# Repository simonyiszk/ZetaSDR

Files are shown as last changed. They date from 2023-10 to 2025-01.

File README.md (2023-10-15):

# ZetaSDR
ZetaSDR HF rádióvevő extra funkciókkal kiegészítve (PLL, USB hangkártya)
zetasdr
Fejlesztői környezet: [https://github.com/Community-PIO-CH32V/platform-ch32v](https://github.com/Community-PIO-CH32V/platform-ch32v).\
Az elektronikai terveket [KiCad](https://www.kicad.org/) seítségével készítettem.

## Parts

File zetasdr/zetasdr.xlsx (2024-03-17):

Reference | Value | Datasheet | Footprint | Qty
C1,C3,C9,C13,C17 | 100n | ~ | Capacitor_SMD:C_0805_2012Metric_Pad1.18x1.45mm_HandSolder | 5
C2,C4 | 22p | ~ | Capacitor_SMD:C_0805_2012Metric_Pad1.18x1.45mm_HandSolder | 2
C5,C6,C7,C8 | 22n | ~ | Capacitor_THT:C_Disc_D3.0mm_W1.6mm_P2.50mm | 4
C10,C12 | 330p | ~ | Capacitor_THT:C_Disc_D3.0mm_W1.6mm_P2.50mm | 2
C11 | 100p | ~ | Capacitor_THT:C_Disc_D3.0mm_W1.6mm_P2.50mm | 1
C14,C15 | 1u | ~ | Capacitor_SMD:C_0805_2012Metric_Pad1.18x1.45mm_HandSolder | 2
C16 | 10u | ~ | Capacitor_THT:CP_Radial_D5.0mm_P2.50mm | 1
D1,D2 | LED | ~ | -- mixed values -- | 2
J1,J4,J9 | OSC | ~ | -- mixed values -- | 6
J2 | USB_B | ~ | Connector_USB:USB_B_Lumberg_2411_02_Horizontal | 1
J3 | USB | ~ | Connector_PinHeader_2.54mm:PinHeader_1x04_P2.54mm_Vertical | 1
J5 | Antenna | ~ | Connector_Coaxial:SMA_Amphenol_901-143_Horizontal | 1
J6 | AudioJack3_SwitchTR | ~ | Connector_Audio:Jack_3.5mm_CUI_SJ1-3525N_Horizontal | 1
J7 | ADC | ~ | Connector_PinHeader_2.54mm:PinHeader_1x04_P2.54mm_Vertical | 1
J8 | FILTER | ~ | Connector_PinHeader_2.54mm:PinHeader_1x04_P2.54mm_Vertical | 1
R1 | 10 | ~ | Resistor_SMD:R_0805_2012Metric_Pad1.20x1.40mm_HandSolder | 1
R2,R3,R7,R8 | 1k | ~ | -- mixed values -- | 4
R4,R5 | 5k1 | ~ | Resistor_THT:R_Axial_DIN0204_L3.6mm_D1.6mm_P5.08mm_Horizontal | 2
R6 | 1M | ~ | Resistor_SMD:R_0805_2012Metric_Pad1.20x1.40mm_HandSolder | 1
U1,U5 | 74AHCT1G14 | http://www.ti.com/lit/sg/scyt129e/scyt129e.pdf | Package_TO_SOT_SMD:SOT-23-5 | 2
U2 | 74HC74 | 74xx/74hc_hct74.pdf | Package_DIP:DIP-14_W7.62mm_Socket_LongPads | 1
U3 | 74HC4052 | http://www.intersil.com/content/dam/Intersil/documents/cd40/cd4051bms-52bms-53bms.pdf | Package_DIP:DIP-16_W7.62mm_Socket_LongPads | 1
U4 | NE5532 | http://www.ti.com/lit/ds/symlink/ne5532.pdf | Package_DIP:DIP-8_W7.62mm_Socket_LongPads | 1
X1 | 28.322MHz | http://cdn-reichelt.de/documents/datenblatt/B400/OSZI.pdf | Oscillator:Oscillator_DIP-8 | 1
Y1 | 14.3594MHz | ~ | Crystal:Crystal_HC49-4H_Vertical | 1
Oszci 40m-re | (7.0805 MHz)
C17 | 100n | ~ | Capacitor_SMD:C_0805_2012Metric_Pad1.18x1.45mm_HandSolder | 1
R8 | 1k | ~ | Resistor_SMD:R_0805_2012Metric_Pad1.20x1.40mm_HandSolder | 1
D2 | LED | ~ | LED_SMD:LED_0805_2012Metric_Pad1.15x1.40mm_HandSolder | 1
J9 | OSC | ~ | Connector_PinSocket_2.54mm:PinSocket_1x03_P2.54mm_Vertical | 2
X1 | 28.322MHz | ECS-2100AX-283.2 (Mouser) | Oscillator:Oscillator_DIP-8 | 1
Oszci 80 m-re | (3.5795 MHz)
C1 | 100n | ~ | Capacitor_SMD:C_0805_2012Metric_Pad1.18x1.45mm_HandSolder | 1
C2,C4 | 22p | ~ | Capacitor_SMD:C_0805_2012Metric_Pad1.18x1.45mm_HandSolder | 2
R1 | 10 | ~ | Resistor_SMD:R_0805_2012Metric_Pad1.20x1.40mm_HandSolder | 1
R6 | 1M | ~ | Resistor_SMD:R_0805_2012Metric_Pad1.20x1.40mm_HandSolder | 1
U1,U5 | 74AHCT1G14 | http://www.ti.com/lit/sg/scyt129e/scyt129e.pdf | Package_TO_SOT_SMD:SOT-23-5 | 2
Y1 | 14.3594MHz | ~ | Crystal:Crystal_HC49-4H_Vertical | 1
J4 | OSC | ~ | Connector_PinSocket_2.54mm:PinSocket_1x03_P2.54mm_Vertical | 2
Alappanel
C3,C9,C13 | 100n | ~ | Capacitor_SMD:C_0805_2012Metric_Pad1.18x1.45mm_HandSolder | 3
C5,C6,C7,C8 | 22n | ~ | Capacitor_THT:C_Disc_D3.0mm_W1.6mm_P2.50mm | 4
C10,C12 | 330p | ~ | Capacitor_THT:C_Disc_D3.0mm_W1.6mm_P2.50mm | 2
C11 | 100p | ~ | Capacitor_THT:C_Disc_D3.0mm_W1.6mm_P2.50mm | 1
C14,C15 | 1u | ~ | Capacitor_SMD:C_0805_2012Metric_Pad1.18x1.45mm_HandSolder | 2
C16 | 10u | ~ | Capacitor_THT:CP_Radial_D5.0mm_P2.50mm | 1
D1 | LED | ~ | LED_THT:LED_D3.0mm | 1
J1 | OSC | ~ | Connector_PinHeader_2.54mm:PinHeader_1x03_P2.54mm_Vertical | 2
J2 | USB_B | ~ | Connector_USB:USB_B_Lumberg_2411_02_Horizontal | 1
J3 | USB | ~ | Connector_PinHeader_2.54mm:PinHeader_1x04_P2.54mm_Vertical | 1
J5 | Antenna | ~ | Connector_Coaxial:SMA_Amphenol_901-143_Horizontal | 1
J6 | AudioJack3_SwitchTR | ~ | Connector_Audio:Jack_3.5mm_CUI_SJ1-3525N_Horizontal | 1
J7 | ADC | ~ | Connector_PinHeader_2.54mm:PinHeader_1x04_P2.54mm_Vertical | 1
J8 | FILTER | ~ | Connector_PinHeader_2.54mm:PinHeader_1x04_P2.54mm_Vertical | 1
R2,R3 | 1k | ~ | Resistor_THT:R_Axial_DIN0204_L3.6mm_D1.6mm_P5.08mm_Horizontal | 2
R7 | 1k | ~ | Resistor_SMD:R_0805_2012Metric_Pad1.20x1.40mm_HandSolder | 1
R4,R5 | 5k1 | ~ | Resistor_THT:R_Axial_DIN0204_L3.6mm_D1.6mm_P5.08mm_Horizontal | 2
U2 | 74HC74 | 74xx/74hc_hct74.pdf | Package_DIP:DIP-14_W7.62mm_Socket_LongPads | 1
U3 | 74HC4052 | http://www.intersil.com/content/dam/Intersil/documents/cd40/cd4051bms-52bms-53bms.pdf | Package_DIP:DIP-16_W7.62mm_Socket_LongPads | 1
U4 | NE5532 | http://www.ti.com/lit/ds/symlink/ne5532.pdf | Package_DIP:DIP-8_W7.62mm_Socket_LongPads | 1
Opcionális IC foglalatok:
U2 | 74HC74 | ~ | Package_DIP:DIP-14_W7.62mm_Socket_LongPads | 1
U3 | 74HC4052 | ~ | Package_DIP:DIP-16_W7.62mm_Socket_LongPads | 1
U4 | NE5532 | ~ | Package_DIP:DIP-8_W7.62mm_Socket_LongPads | 1

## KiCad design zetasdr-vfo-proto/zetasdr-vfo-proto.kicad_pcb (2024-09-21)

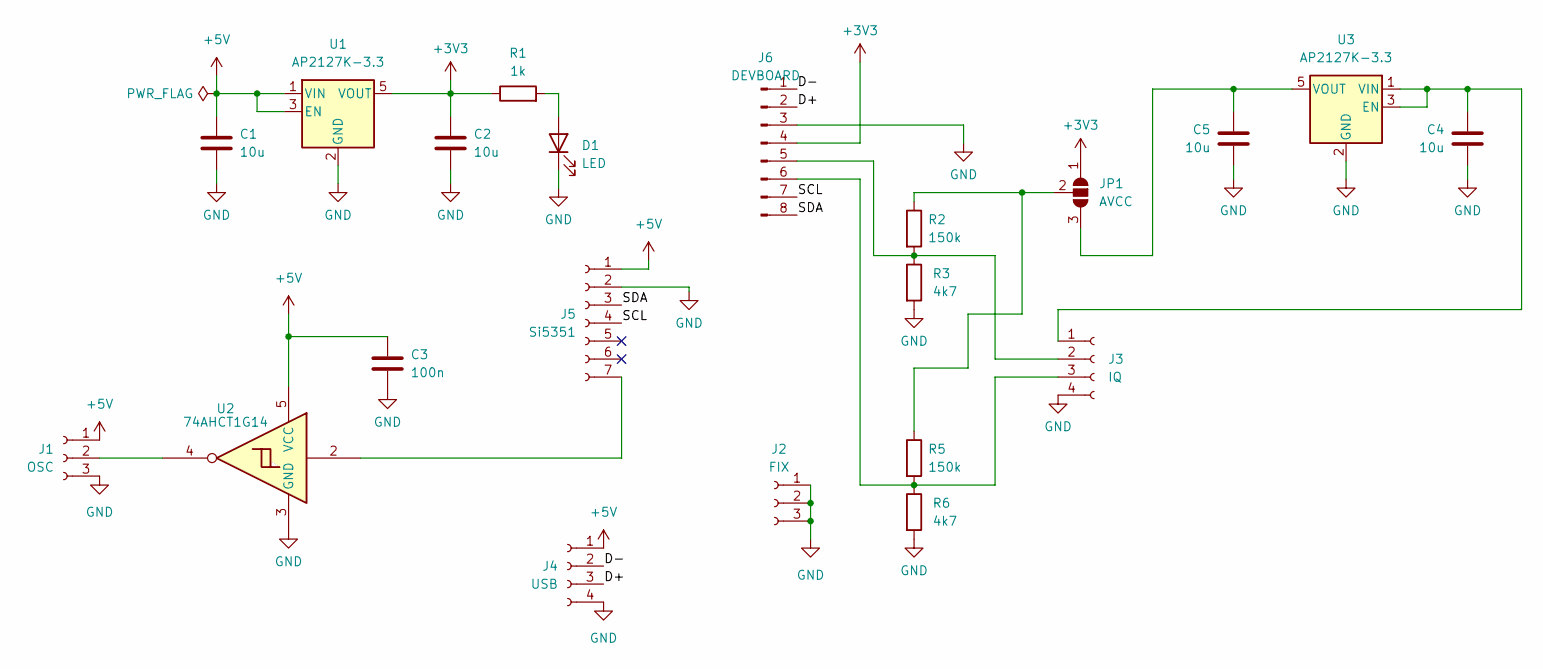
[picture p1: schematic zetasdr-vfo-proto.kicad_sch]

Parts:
C1, C2, C4, C5: 10u; C_0805_2012Metric_Pad1.18x1.45mm_HandSolder
C3: 100n; C_0805_2012Metric_Pad1.18x1.45mm_HandSolder
D1: LED; LED_0805_2012Metric_Pad1.15x1.40mm_HandSolder
J1: OSC; PinSocket_1x03_P2.54mm_Vertical
J2: FIX; PinSocket_1x03_P2.54mm_Vertical
J3: IQ; PinSocket_1x04_P2.54mm_Vertical
J4: USB; PinSocket_1x04_P2.54mm_Vertical
J5: Si5351; PinSocket_1x07_P2.54mm_Horizontal
J6: DEVBOARD; PinHeader_1x08_P2.54mm_Vertical
JP1: AVCC; SolderJumper-3_P1.3mm_Open_RoundedPad1.0x1.5mm
R1: 1k; R_0805_2012Metric_Pad1.20x1.40mm_HandSolder
R2, R5: 150k; R_0805_2012Metric_Pad1.20x1.40mm_HandSolder
R3, R6: 4k7; R_0805_2012Metric_Pad1.20x1.40mm_HandSolder
U1, U3: AP2127K-3.3; SOT-23-5_HandSoldering
U2: 74AHCT1G14; SOT-23-5_HandSoldering

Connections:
+3V3: C2.1, J6.4, JP1.1 (A), R1.1, U1.5 (VOUT)
+5V: C1.1, C3.1, J1.1, J4.1, J5.1, U1.1 (VIN), U1.3 (EN), U2.5 (VCC)
/D+: J4.3, J6.2
/D-: J4.2, J6.1
/SCL: J5.4, J6.7
/SDA: J5.3, J6.8
GND: C1.2, C2.2, C3.2, C4.2, C5.2, D1.1 (K), J1.3, J2.1, J2.2, J2.3, J3.4, J4.4, J5.2, J6.3, R3.2, R6.2, U1.2 (GND), U2.3 (GND), U3.2 (GND)
unnamed: D1.2 (A), R1.2
unnamed: J1.2, U2.4
unnamed: C4.1, J3.1, U3.1 (VIN), U3.3 (EN)
unnamed: J3.2, J6.5, R2.2, R3.1
unnamed: J3.3, J6.6, R5.2, R6.1
unnamed: J5.7, U2.2
unnamed: C5.1, JP1.3 (B), U3.5 (VOUT)
unnamed: JP1.2 (C), R2.1, R5.1

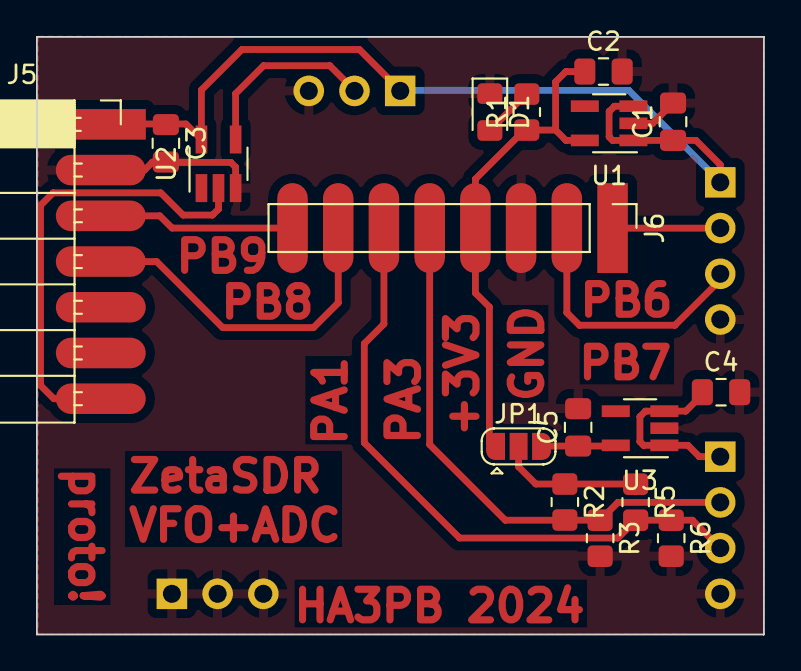
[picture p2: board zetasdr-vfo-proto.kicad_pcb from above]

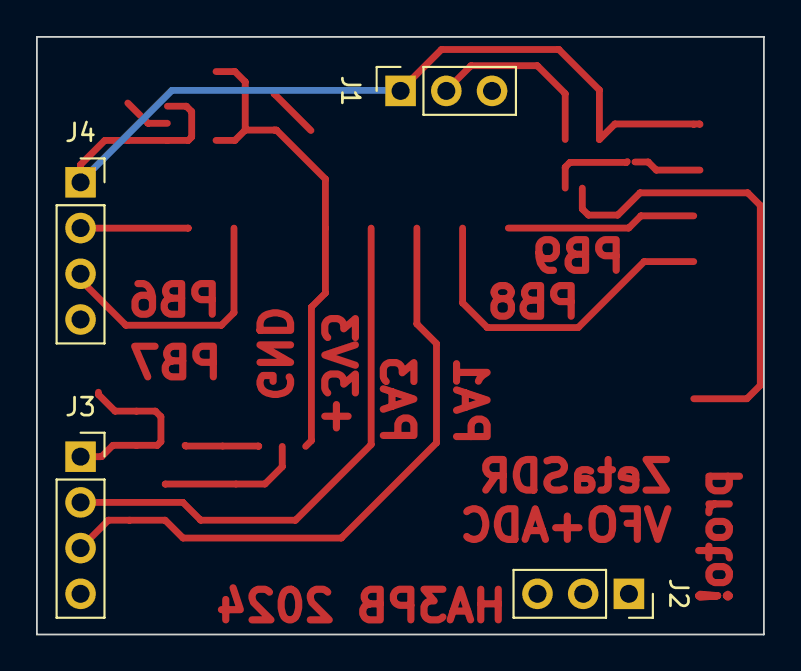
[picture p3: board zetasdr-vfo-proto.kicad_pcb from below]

Board: 2 copper layers, 40.4 x 33.2 mm, 21 parts (4 on the bottom side), 15 nets.

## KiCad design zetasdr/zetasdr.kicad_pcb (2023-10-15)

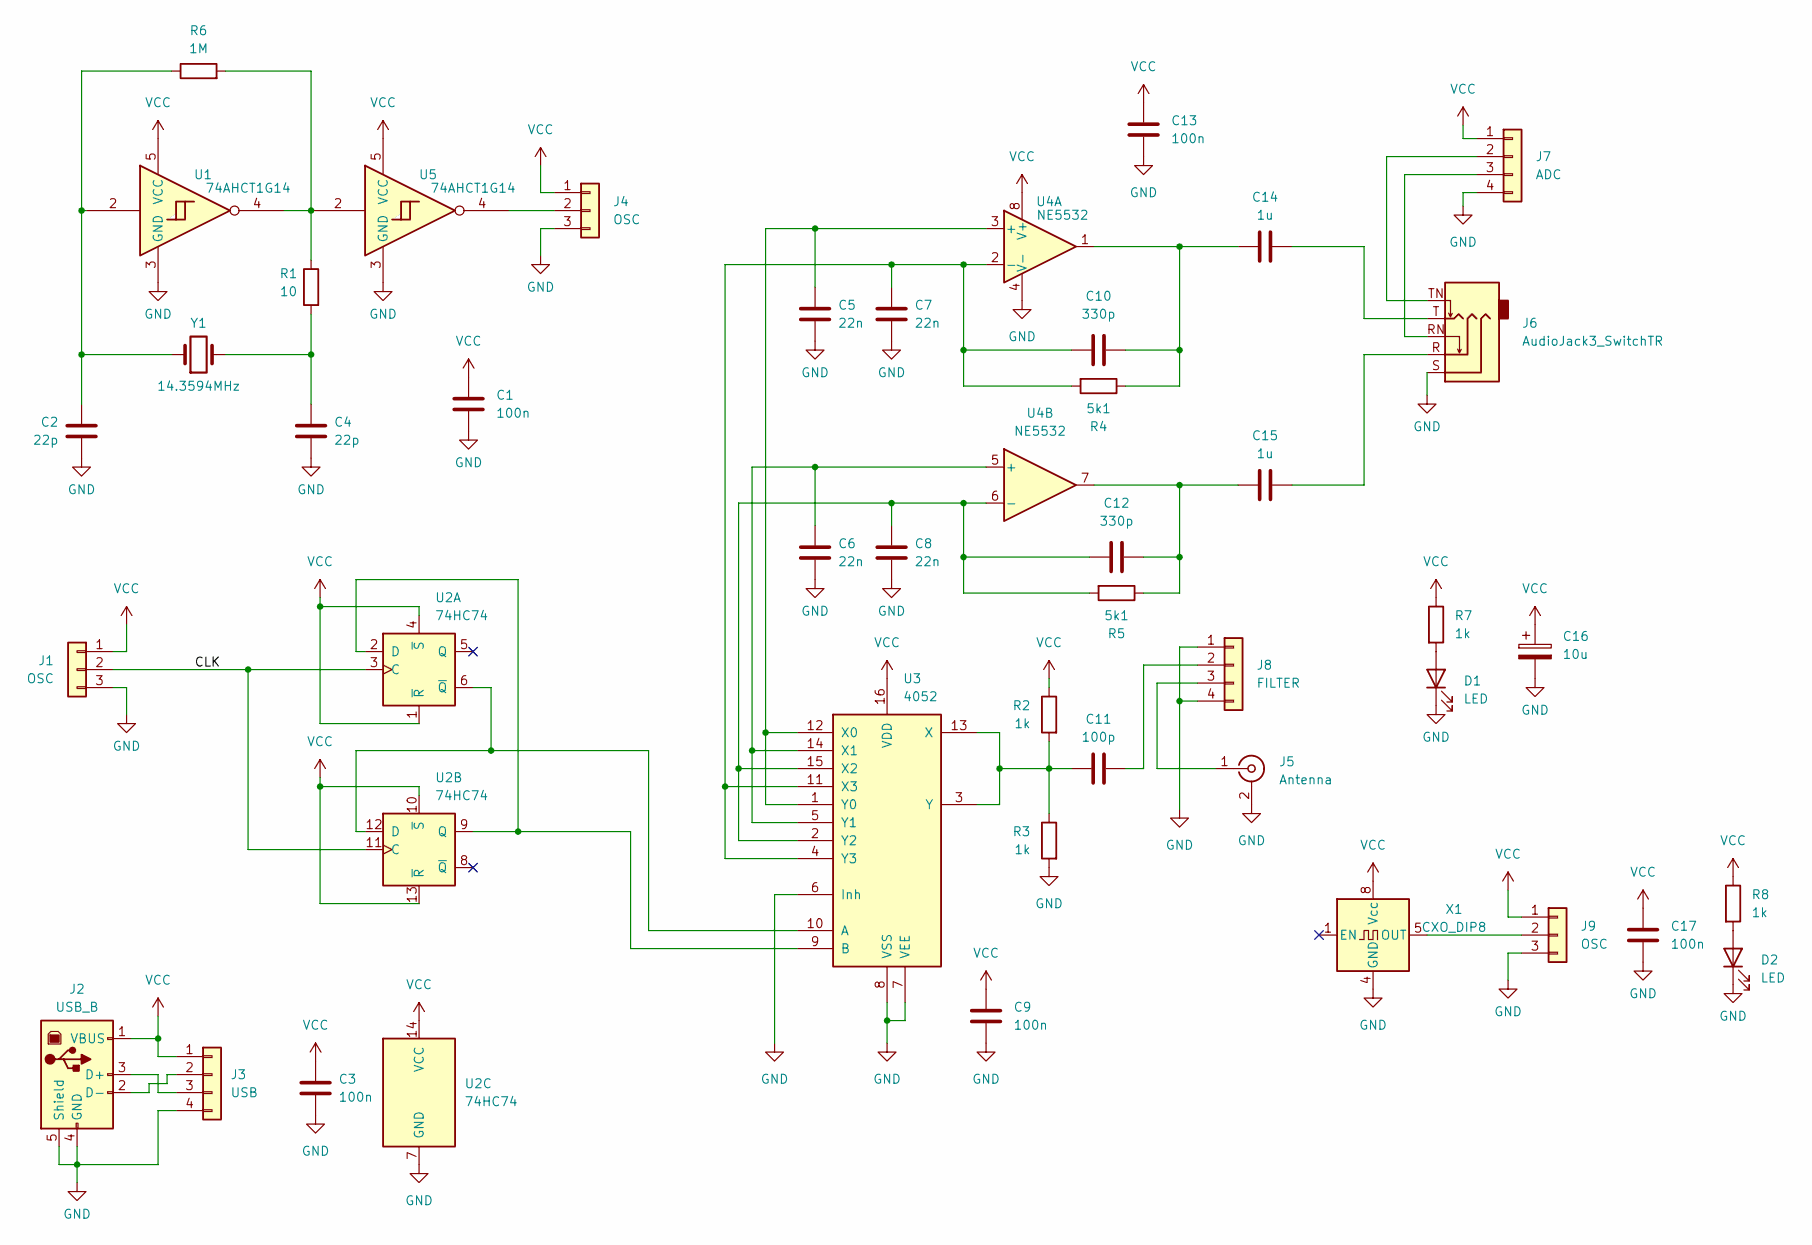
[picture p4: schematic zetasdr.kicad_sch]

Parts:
C1, C3, C9, C13, C17: 100n; C_0805_2012Metric_Pad1.18x1.45mm_HandSolder
C2, C4: 22p; C_0805_2012Metric_Pad1.18x1.45mm_HandSolder
C5, C6, C7, C8: 22n; C_Disc_D3.0mm_W1.6mm_P2.50mm
C10, C12: 330p; C_Disc_D3.0mm_W1.6mm_P2.50mm
C11: 100p; C_Disc_D3.0mm_W1.6mm_P2.50mm
C14, C15: 1u; C_0805_2012Metric_Pad1.18x1.45mm_HandSolder
C16: 10u; CP_Radial_D5.0mm_P2.50mm
D1: LED; LED_D3.0mm
D2: LED; LED_0805_2012Metric_Pad1.15x1.40mm_HandSolder
J1: OSC; PinHeader_1x03_P2.54mm_Vertical
J2: USB_B; USB_B_Lumberg_2411_02_Horizontal
J3: USB; PinHeader_1x04_P2.54mm_Vertical
J4, J9: OSC; PinSocket_1x03_P2.54mm_Vertical
J5: Antenna; SMA_Amphenol_901-143_Horizontal
J6: AudioJack3_SwitchTR; Jack_3.5mm_CUI_SJ1-3525N_Horizontal
J7: ADC; PinHeader_1x04_P2.54mm_Vertical
J8: FILTER; PinHeader_1x04_P2.54mm_Vertical
R1: 10; R_0805_2012Metric_Pad1.20x1.40mm_HandSolder
R2, R3: 1k; R_Axial_DIN0204_L3.6mm_D1.6mm_P5.08mm_Horizontal
R4, R5: 5k1; R_Axial_DIN0204_L3.6mm_D1.6mm_P5.08mm_Horizontal
R6: 1M; R_0805_2012Metric_Pad1.20x1.40mm_HandSolder
R7, R8: 1k; R_0805_2012Metric_Pad1.20x1.40mm_HandSolder
U1, U5: 74AHCT1G14; SOT-23-5
U2: 74HC74; DIP-14_W7.62mm_Socket_LongPads
U3: 4052; DIP-16_W7.62mm_Socket_LongPads
U4: NE5532; DIP-8_W7.62mm_Socket_LongPads
X1: CXO_DIP8; Oscillator_DIP-8
Y1: 14.3594MHz; Crystal_HC49-4H_Vertical

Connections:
/CLK: J1.2, U2.3 (C), U2.11 (C)
GND: C1.2, C2.2, C3.2, C4.2, C5.2, C6.2, C7.2, C8.2, C9.1, C13.1, C16.2, C17.2, D1.1 (K), D2.1 (K), J1.3, J2.4 (GND), J2.5 (Shield), J3.4, J4.3, J5.2 (Ext), J6.S, J7.4, J8.1, J8.4, J9.3, R3.2, U1.3 (GND), U2.7 (GND), U3.6 (Inh), U3.7 (VEE), U3.8 (VSS), U4.4 (V-), U5.3 (GND), X1.4 (GND)
unnamed: C2.1, R6.1, U1.2, Y1.1
unnamed: C4.1, R1.2, Y1.2
unnamed: C10.2, C14.1, R4.1, U4.1
unnamed: C12.2, C15.1, R5.1, U4.7
unnamed: C14.2, J6.T
unnamed: C15.2, J6.R
unnamed: D1.2 (A), R7.2
unnamed: D2.2 (A), R8.2
unnamed: J2.3 (D+), J3.3
unnamed: J2.2 (D-), J3.2
unnamed: J4.2, U5.4
unnamed: J5.1 (In), J8.3
unnamed: J6.TN, J7.2
unnamed: J6.RN, J7.3
unnamed: C11.2, J8.2
unnamed: J9.2, X1.5 (OUT)
unnamed: R1.1, R6.2, U1.4, U5.2
unnamed: U2.2 (D), U2.9 (Q), U3.9 (B)
unnamed: U2.6 (~Q), U2.12 (D), U3.10 (A)
unnamed: C5.1, U3.1 (Y0), U3.12 (X0), U4.3 (+)
unnamed: C6.1, U3.5 (Y1), U3.14 (X1), U4.5 (+)
unnamed: C8.1, C12.1, R5.2, U3.2 (Y2), U3.15 (X2), U4.6 (-)
unnamed: C7.1, C10.1, R4.2, U3.4 (Y3), U3.11 (X3), U4.2 (-)
unnamed: C11.1, R2.2, R3.1, U3.3 (Y), U3.13 (X)
VCC: C1.1, C3.1, C9.2, C13.2, C16.1, C17.1, J1.1, J2.1 (VBUS), J3.1, J4.1, J7.1, J9.1, R2.1, R7.1, R8.1, U1.5 (VCC), U2.1 (~R), U2.4 (~S), U2.10 (~S), U2.13 (~R), U2.14 (VCC), U3.16 (VDD), U4.8 (V+), U5.5 (VCC), X1.8 (Vcc)

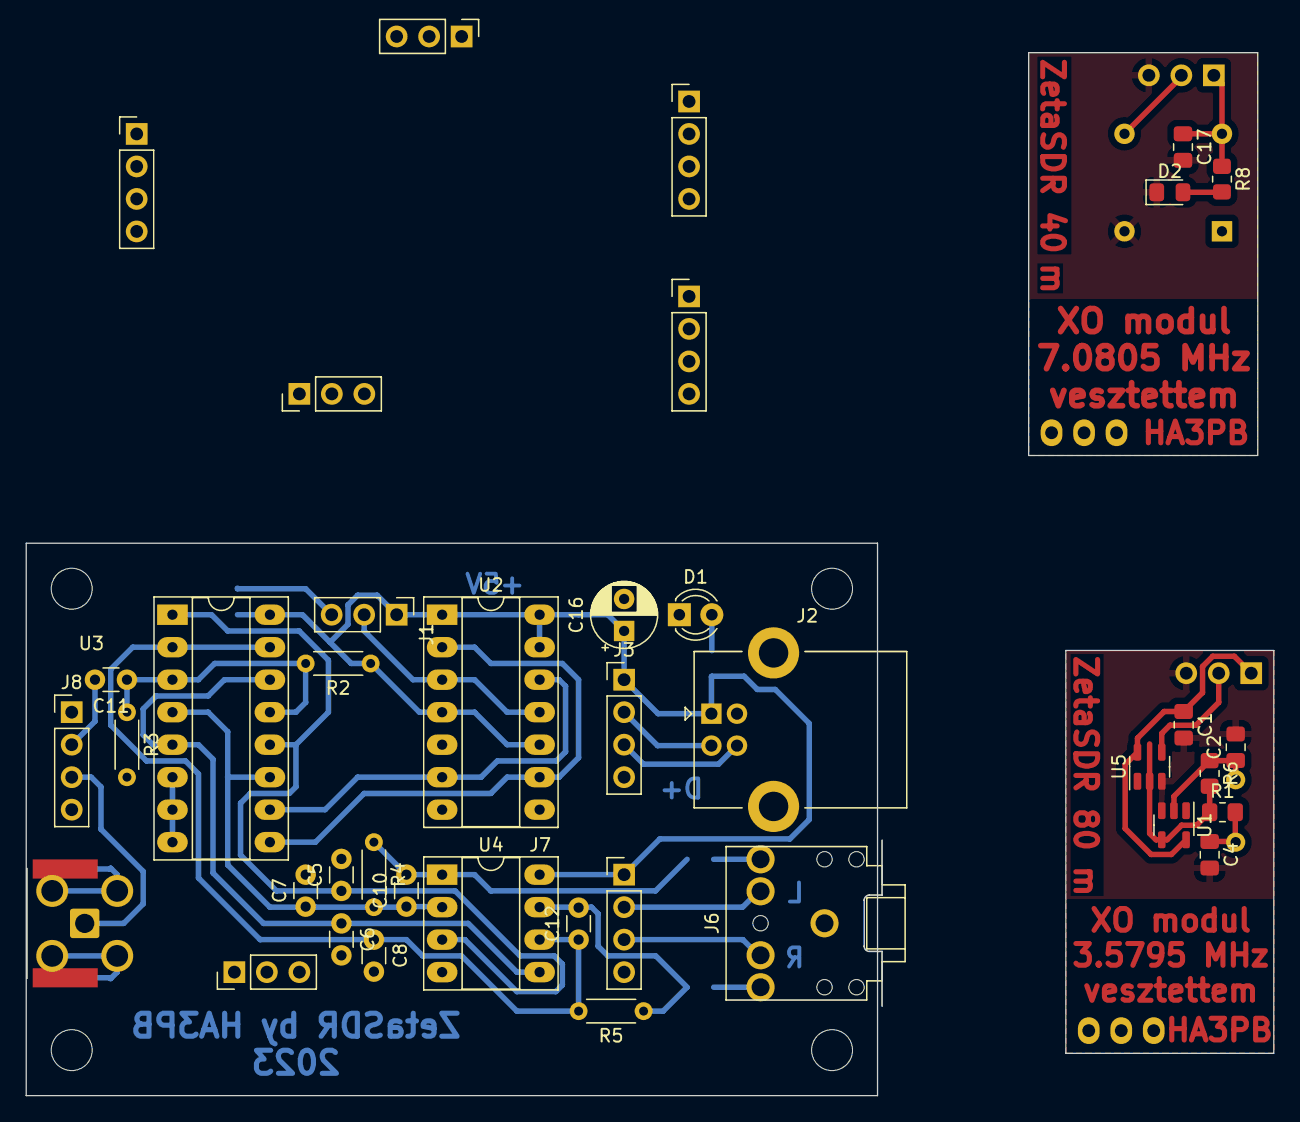
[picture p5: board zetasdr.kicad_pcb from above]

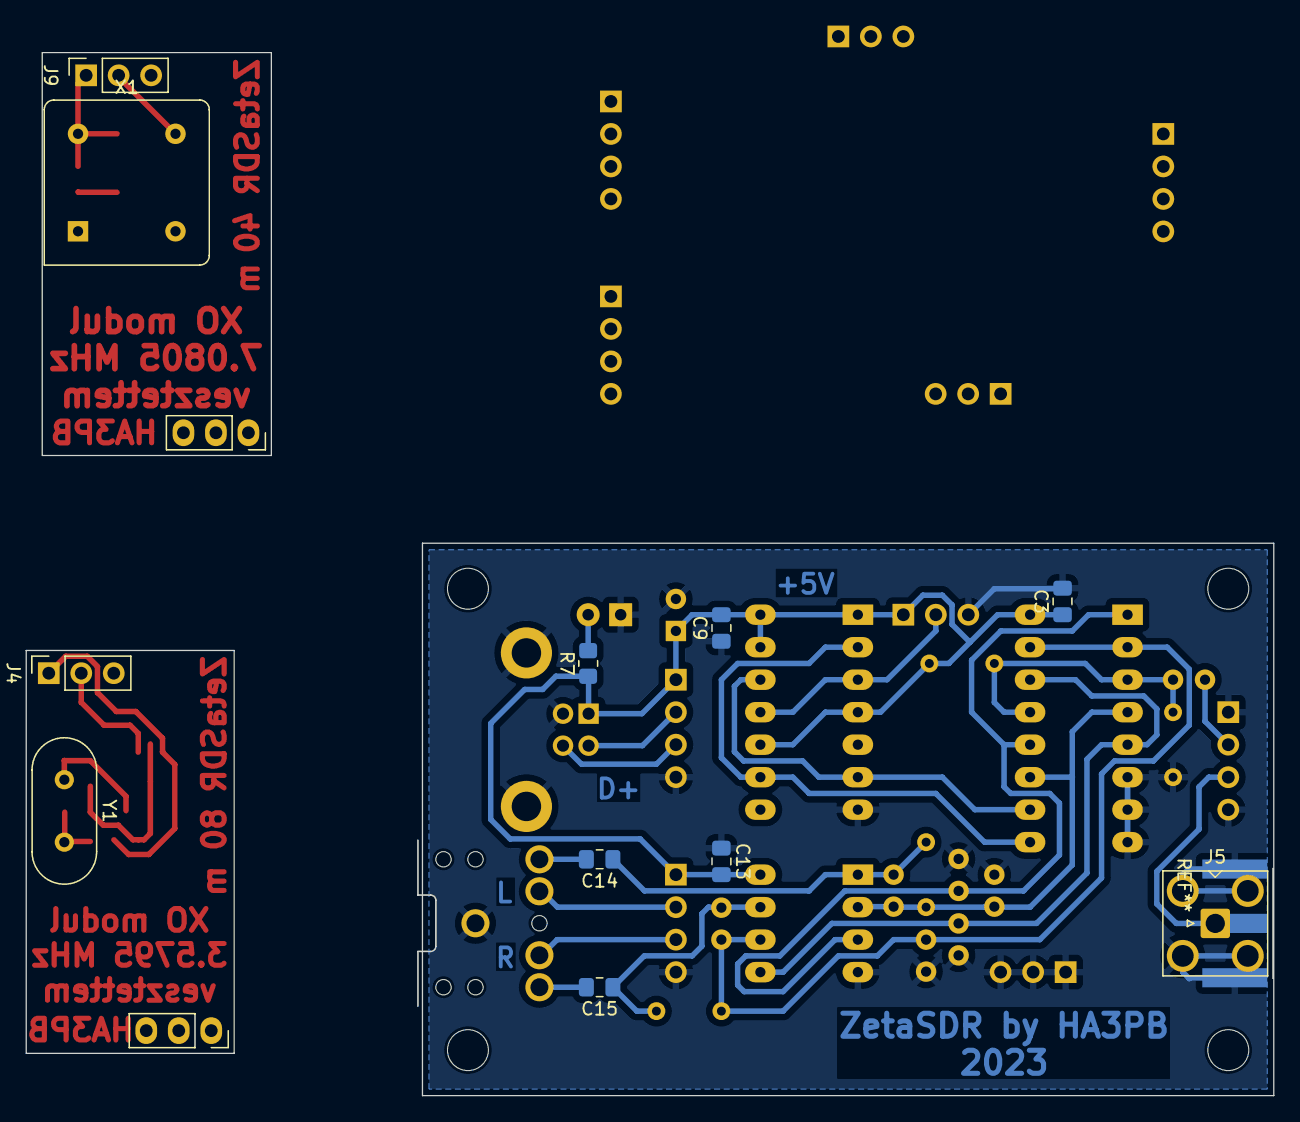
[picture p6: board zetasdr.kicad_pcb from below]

Board: 2 copper layers, 97.5 x 81.5 mm, 47 parts (11 on the bottom side), 27 nets.

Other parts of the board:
J?: ADC; PinHeader_1x04_P2.54mm_Vertical
J?#2: USB; PinHeader_1x04_P2.54mm_Vertical
J?#3: FILTER; PinHeader_1x04_P2.54mm_Vertical
J?#4: OSC; PinHeader_1x03_P2.54mm_Vertical

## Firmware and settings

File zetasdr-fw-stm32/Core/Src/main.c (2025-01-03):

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
/* Includes ------------------------------------------------------------------*/
#include "main.h"
#include "adc.h"
#include "tim.h"
#include "usart.h"
#include "usb_otg.h"
#include "gpio.h"

/* USER CODE BEGIN Includes */
#include "tusb.h"
#include "tusb_config.h"
#include "cdc.h"
#include "audio.h"
/* USER CODE END Includes */

/* USER CODE BEGIN PTD */
/* Blink pattern
 * - 250 ms  : device not mounted
 * - 100 ms  : device mounted
 * - 1000 ms : device is suspended
 */
enum {
  BLINK_NOT_MOUNTED = 250,
  BLINK_MOUNTED = 100,
  BLINK_SUSPENDED = 1000
};
/* USER CODE END PTD */


/* USER CODE BEGIN PV */

static uint32_t blink_interval_ms = BLINK_NOT_MOUNTED;

/* USER CODE END PV */

void SystemClock_Config(void);
/* USER CODE BEGIN PFP */
void led_blinking_task(void);
void audio_task(void);
/* USER CODE END PFP */

/* USER CODE BEGIN 0 */

//--------------------------------------------------------------------+
// Device callbacks
//--------------------------------------------------------------------+

// Invoked when device is mounted
void tud_mount_cb(void)
{
  blink_interval_ms = BLINK_MOUNTED;
}

// Invoked when device is unmounted
void tud_umount_cb(void)
{
  blink_interval_ms = BLINK_NOT_MOUNTED;
}

// Invoked when usb bus is suspended
void tud_suspend_cb(bool remote_wakeup_en)
{
  (void) remote_wakeup_en;
  blink_interval_ms = BLINK_SUSPENDED;
}

// Invoked when usb bus is resumed
void tud_resume_cb(void)
{
  blink_interval_ms = tud_mounted() ? BLINK_MOUNTED : BLINK_NOT_MOUNTED;
}

//--------------------------------------------------------------------+
// BLINKING TASK
//--------------------------------------------------------------------+
void led_blinking_task(void)
{
  static uint32_t start_ms = 0;
  static bool led_state = false;

  // Blink every interval ms
  if ( HAL_GetTick() - start_ms < blink_interval_ms) return; // not enough time
  start_ms += blink_interval_ms;

  HAL_GPIO_WritePin(DEBUG_LED_GPIO_Port, DEBUG_LED_Pin, led_state);  
  led_state = 1 - led_state; // toggle
}

/* USER CODE END 0 */

/**
  * @brief  The application entry point.
  * @retval int
  */
int main(void)
{

  /* MCU Configuration--------------------------------------------------------*/

  /* Reset of all peripherals, Initializes the Flash interface and the Systick. */
  HAL_Init();

  /* Configure the system clock */
  SystemClock_Config();

  /* Initialize all configured peripherals */
  MX_GPIO_Init();
  MX_ADC1_Init();
  MX_TIM2_Init();
  MX_USART2_UART_Init();
  MX_USB_OTG_FS_PCD_Init();
  /* USER CODE BEGIN 2 */

  // init device stack on configured roothub port
  tusb_rhport_init_t dev_init = {
    .role = TUSB_ROLE_DEVICE,
    .speed = TUSB_SPEED_AUTO
  };
  tusb_init(BOARD_TUD_RHPORT, &dev_init);

  audio_init();

  /* Single ADC ued for sampling IN0 and IN1 channels
    IN0 sampled in regular mode @ Timer2 update event (overflow)
    IN1 sampled in injected mode @ Timer2 compare event (half of every period, compare value = 187) <- modify in CubeMX to change phase shift between the two channels
    f_TIM = 72MHz, prescale = 0, period = 375-1 (to match fs = 192kHz)
  */
  HAL_ADCEx_InjectedStart_IT(&hadc1);
  HAL_ADC_Start_IT(&hadc1);
  HAL_TIM_Base_Start(&htim2);
  HAL_TIM_PWM_Start(&htim2, TIM_CHANNEL_1);
 
  /* USER CODE END 2 */

  /* Infinite loop */
  /* USER CODE BEGIN WHILE */
  while (1)
  {
    /* USER CODE END WHILE */

    /* USER CODE BEGIN 3 */
    tud_task(); // tinyusb device task
    led_blinking_task();
    audio_task();
    cdc_task(); // virtual serial port
  }
  /* USER CODE END 3 */
}

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
/* USER CODE BEGIN 4 */
int __io_putchar(int ch)
{
  HAL_UART_Transmit(&huart2, (uint8_t *)&ch, 1, 0xFFFF);
  return ch;
}
/* USER CODE END 4 */
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


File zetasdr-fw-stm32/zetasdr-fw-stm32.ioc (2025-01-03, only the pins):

Mcu.UserName=STM32F401RCTx
PA0-WKUP.Signal=ADCx_IN0
PA1.Signal=ADCx_IN1
PA11.GPIO_Label=USB_DM
PA11.Signal=USB_OTG_FS_DM
PA12.GPIO_Label=USB_DP
PA12.Signal=USB_OTG_FS_DP
PA13.GPIO_Label=SWDIO
PA13.Signal=SYS_JTMS-SWDIO
PA14.GPIO_Label=SWCLK
PA14.Signal=SYS_JTCK-SWCLK
PA2.Signal=USART2_TX
PA3.Signal=USART2_RX
PA5.GPIO_Label=DEBUG_LED
PA5.Signal=GPIO_Output

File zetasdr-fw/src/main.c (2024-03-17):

#include <ch32v20x.h>
#include <stdlib.h>
#include "adc.h"
#include "tim.h"
#include "si5351.h"
#include "ch32v20x_usbfs_device.h"

int main(void){

    Si5351_I2C_Init(100000, 0);
    Si5351_ConfigTypeDef VFO;
    Si5351_StructInit(&VFO);
    Si5351_Init(&VFO);

    USBFS_RCC_Init();
    USBFS_Device_Init(ENABLE);

    ADC_Function_Init();
    ADC_ExternalTrigConvCmd(ADC1, ENABLE);

    TIM1_OutCompare_Init(249, 1, 50);

	GPIO_InitTypeDef GPIO_InitStructure={0};

    GPIO_InitStructure.GPIO_Pin = GPIO_Pin_9; 	// debug pin
	GPIO_InitStructure.GPIO_Mode = GPIO_Mode_Out_PP;
	GPIO_InitStructure.GPIO_Speed = GPIO_Speed_50MHz;
	GPIO_Init( GPIOA, &GPIO_InitStructure );

    while(1){
        if(UARTPacketReceived==SET){
            Si5351_SetVFOFreq(UART_VFO_target * 4, &VFO, 0);
            UARTPacketReceived = RESET;
        }
    }
}

// Problémák: a si5351 néha egyszer csak már nem állítja a frekvenciákat, hiába küldöm az adatokat neki
// az USB hangkártya nagyon shitty, a spektrumban rengeteg pöcök van a 0 körül és nem látszik semmi értelmes jel :(

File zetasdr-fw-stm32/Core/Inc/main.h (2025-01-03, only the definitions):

#define DEBUG_LED_Pin GPIO_PIN_5
#define DEBUG_LED_GPIO_Port GPIOA
#define USB_DM_Pin GPIO_PIN_11
#define USB_DM_GPIO_Port GPIOA
#define USB_DP_Pin GPIO_PIN_12
#define USB_DP_GPIO_Port GPIOA
#define SWDIO_Pin GPIO_PIN_13
#define SWDIO_GPIO_Port GPIOA
#define SWCLK_Pin GPIO_PIN_14
#define SWCLK_GPIO_Port GPIOA

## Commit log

2023-10-15 Add schematic and pcb design
    [zetasdr.kicad_pcb, zetasdr.kicad_sch]
2023-10-15 Add sound card firmware for CH32V203 eval board
2024-03-17 Add fancy BOM
    [zetasdr.xlsx]
2024-03-17 Add firmware
    Composite USB device w/ stereo analog input & virtual serial port.
    Features:
    192kHz 12-bit stereo ADC IN.
    Composite USB device with unique yet standard hand-made descriptor.
    Center frequency can be set via serial port (desired value is being set by configuring an Si5351 VFO via I2C)
    DC removal digital IIR filter implemented using fixed-point arithmetic.
    [adc.c, ch32v20x_it.c, main.c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]
2024-09-20 Add basic vfo shield
    [zetasdr-vfo-shield.kicad_pcb, zetasdr-vfo-shield.kicad_sch]
2024-09-21 Add adapter board for vfo shield testing purposes
    [zetasdr-vfo-proto.kicad_pcb, zetasdr-vfo-proto.kicad_sch]
2025-01-03 Basic firmware for STM32
    Tested on a STM32 Redpill board (https://github.com/simonyiszk/STM32-RedPill).
    Generate code in CubeMX to obtain CMSIS and HAL Drivers & Clone tinyusb repository(https://github.com/hathach/tinyusb) into Libs folder to get everything working

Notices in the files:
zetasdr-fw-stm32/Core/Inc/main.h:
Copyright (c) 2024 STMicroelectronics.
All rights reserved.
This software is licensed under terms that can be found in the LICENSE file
